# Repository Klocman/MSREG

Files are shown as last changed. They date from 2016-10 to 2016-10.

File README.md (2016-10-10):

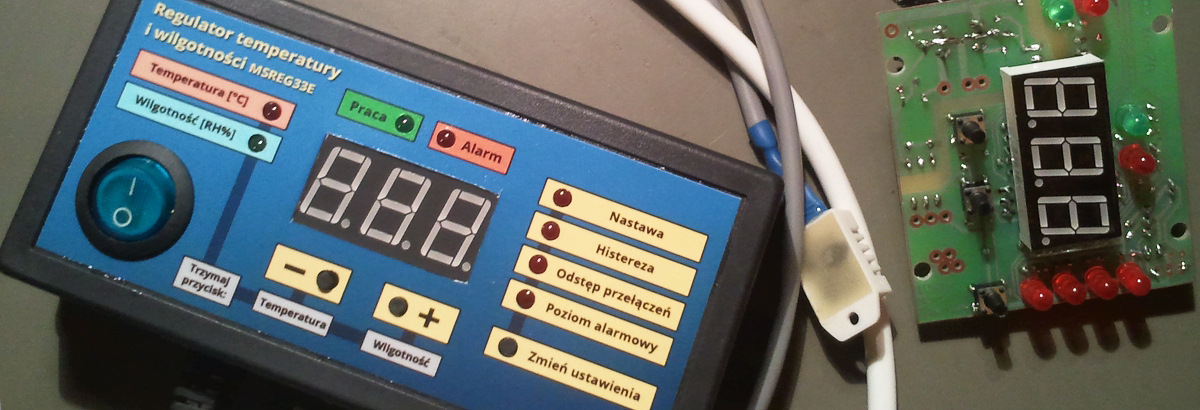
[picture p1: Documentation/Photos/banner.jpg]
Finished regulator, and a partially assembled board

## MSREG (Most recently MSREG33E)
Temperature and (optionally) humidity regulator based on DS18B20 or DHT22 sensors. This project contains the board layout, firmware, bootloader, and Windows tools that can be used with the regulator to monitor, configure, and update it. 

This regulator can be used for terrariums, heaters, egg incubators, refrigerators - anything that depends on stable temperature and/or humidity, and can be controlled by turning something On or Off.

## Features and technical specifications
[Read the datasheet (only in Polish at the moment)](https://github.com/Klocman/MSREG/blob/master/Documentation/datasheet_pl_msreg33E_r7.pdf)

## Compiling / Software required
Boards and schematics were created with Eagle PCB v6.6.0. 

Firmare and Bootloader can be opened and compiled with Atmel Studio 6 or newer. The bootloader .hex has to be manually merged with the main firmware .hex.

The Windows applications can be compiled in any modern version of Visual Studio with C# support.

## Photos and videos of the regulator
[Youtube video of MSREG33E working with the Windows application](https://youtu.be/d277WWdbOqA?t=52s)

[You can view the full gallery here](https://github.com/Klocman/MSREG/tree/master/Documentation/Photos)

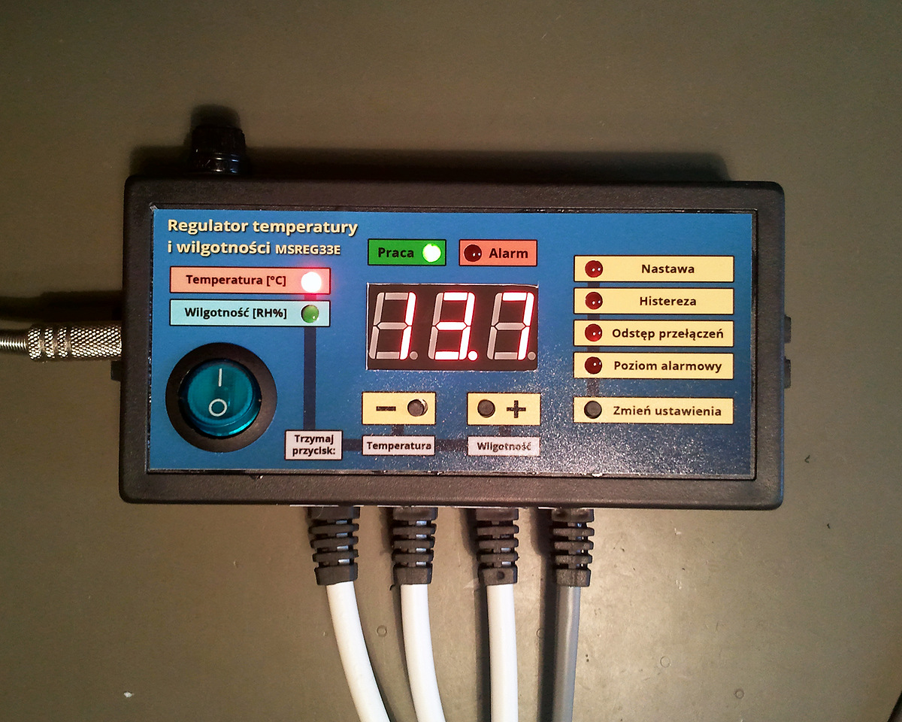
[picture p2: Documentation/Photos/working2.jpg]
Fully assembled and turned on

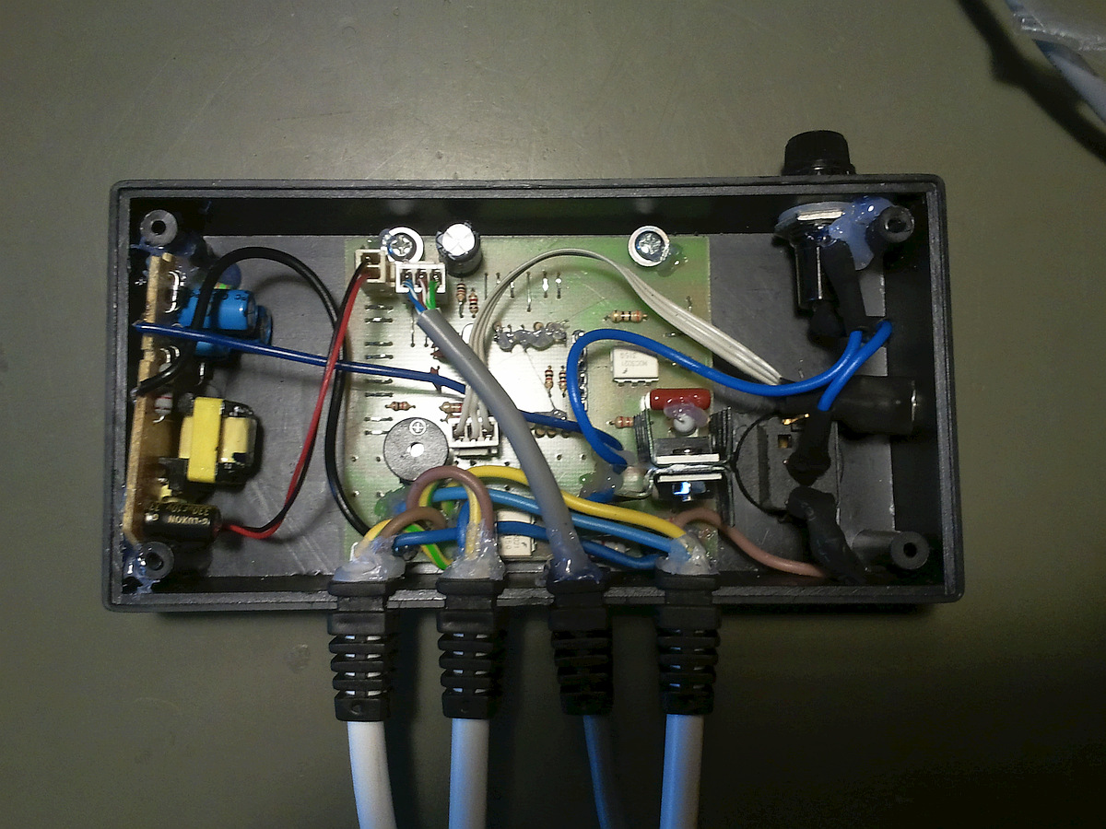
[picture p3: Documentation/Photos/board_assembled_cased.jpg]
Fully assembled with the back removed

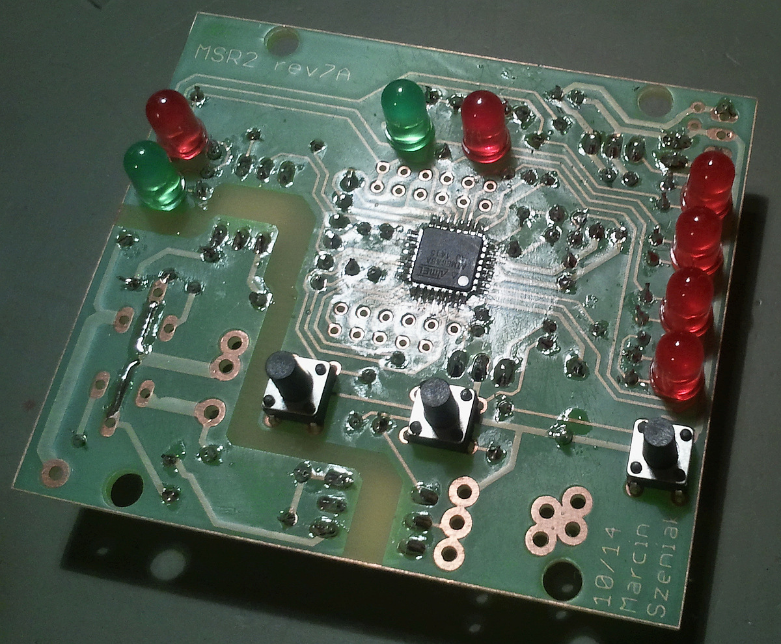
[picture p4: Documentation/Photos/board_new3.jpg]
Front of a partially assembled board

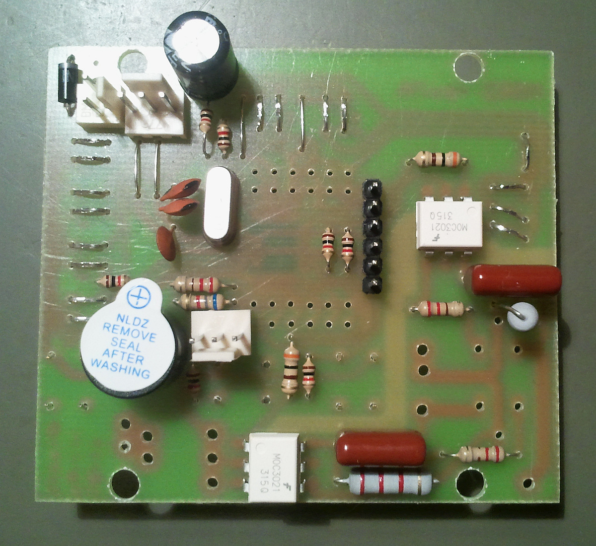
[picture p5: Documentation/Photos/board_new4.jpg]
Back of a partially assembled board


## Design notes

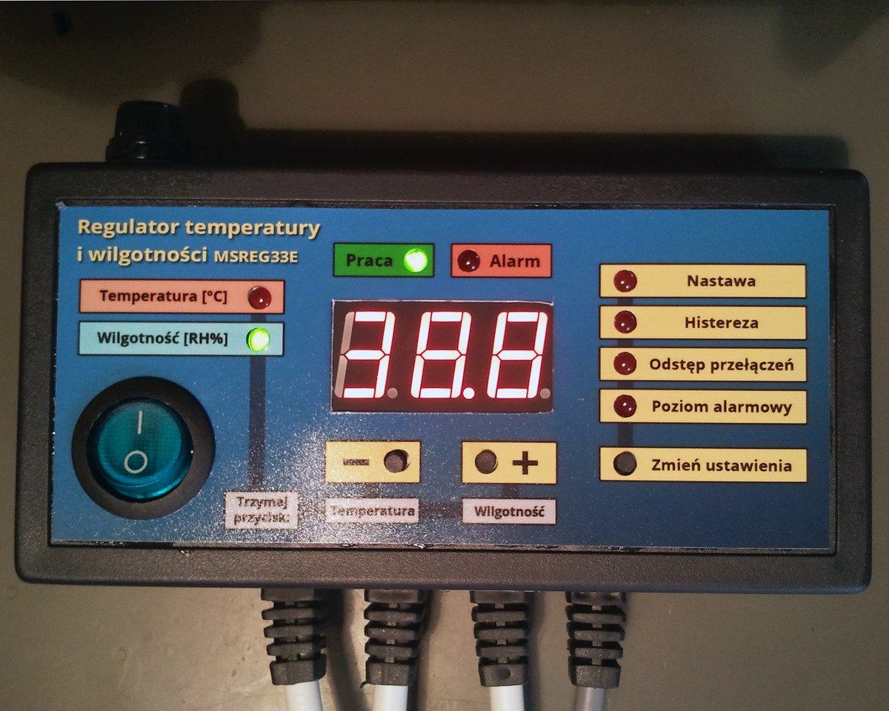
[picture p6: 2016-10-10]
Documentation/Photos/working1.jpg

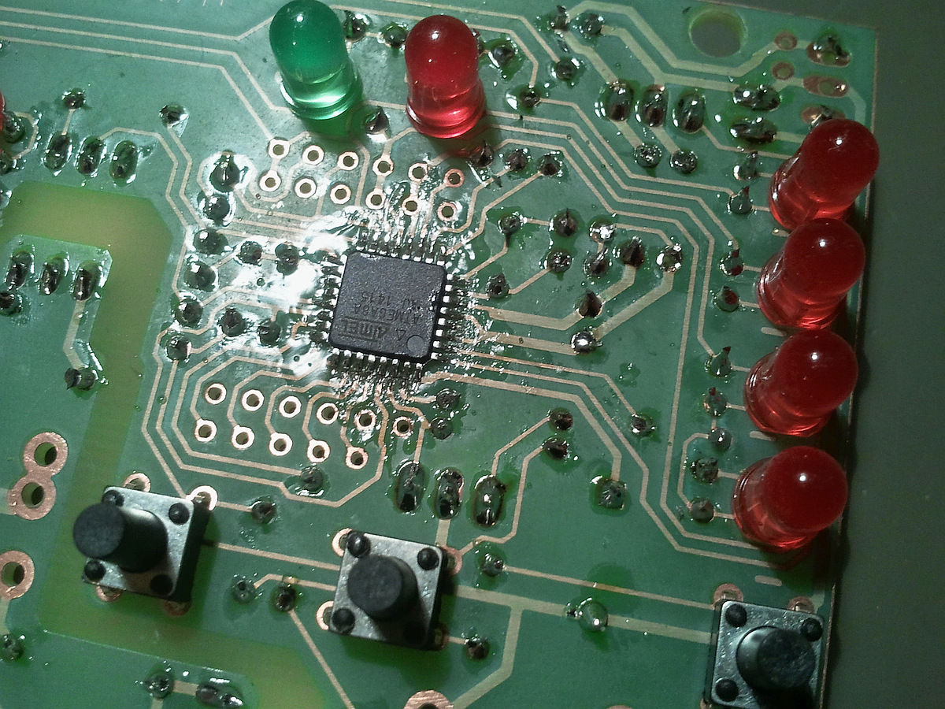
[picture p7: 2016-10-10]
Documentation/Photos/board_new2.jpg

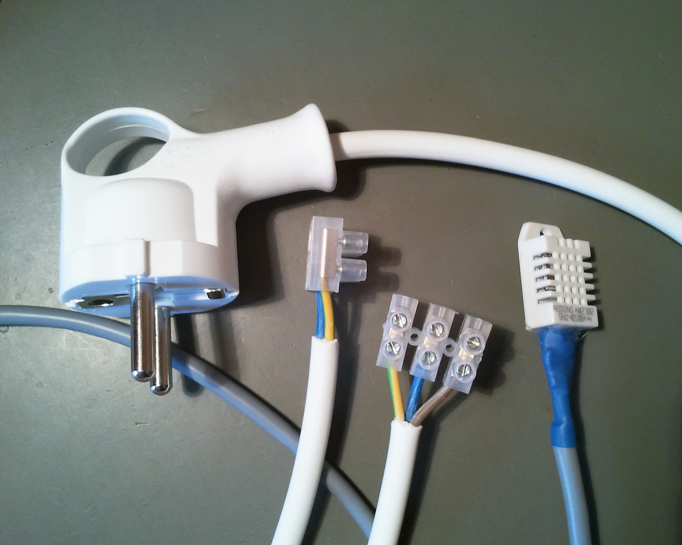
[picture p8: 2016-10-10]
Documentation/Photos/working6.jpg

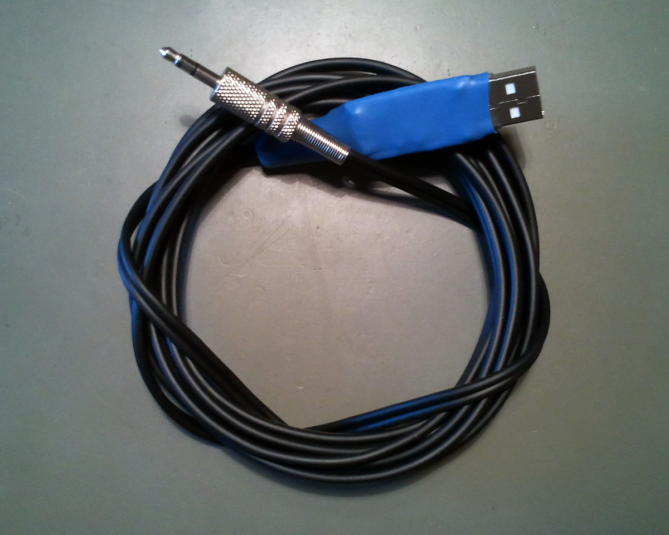
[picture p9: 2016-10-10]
Documentation/Photos/cable.jpg

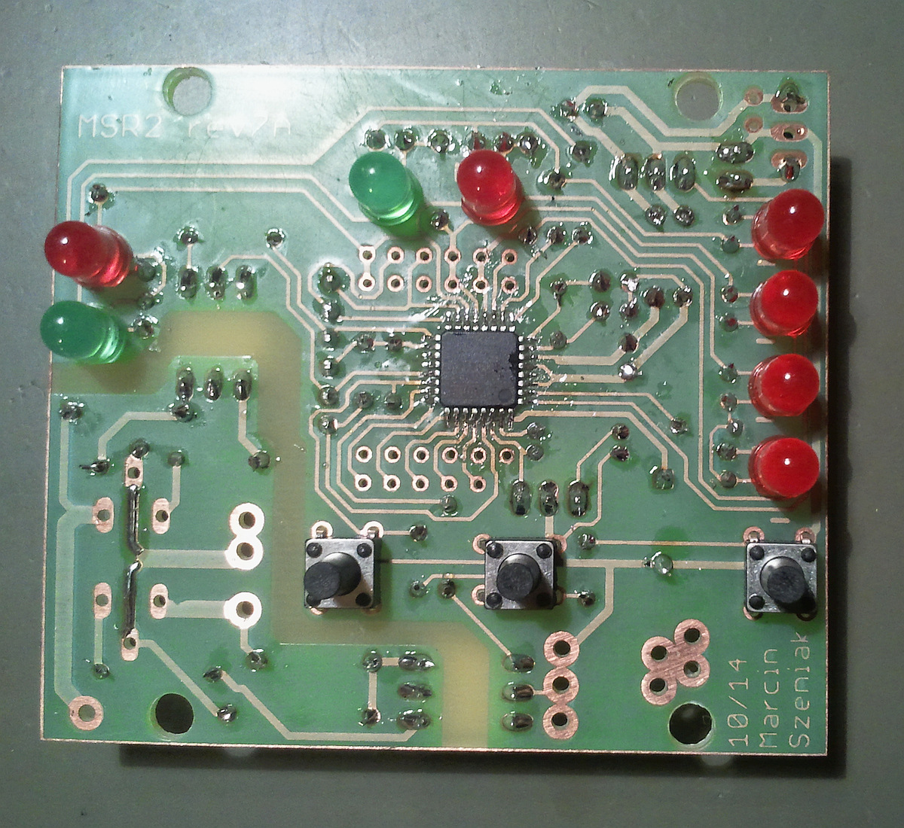
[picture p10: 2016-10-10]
Documentation/Photos/board_new1.jpg

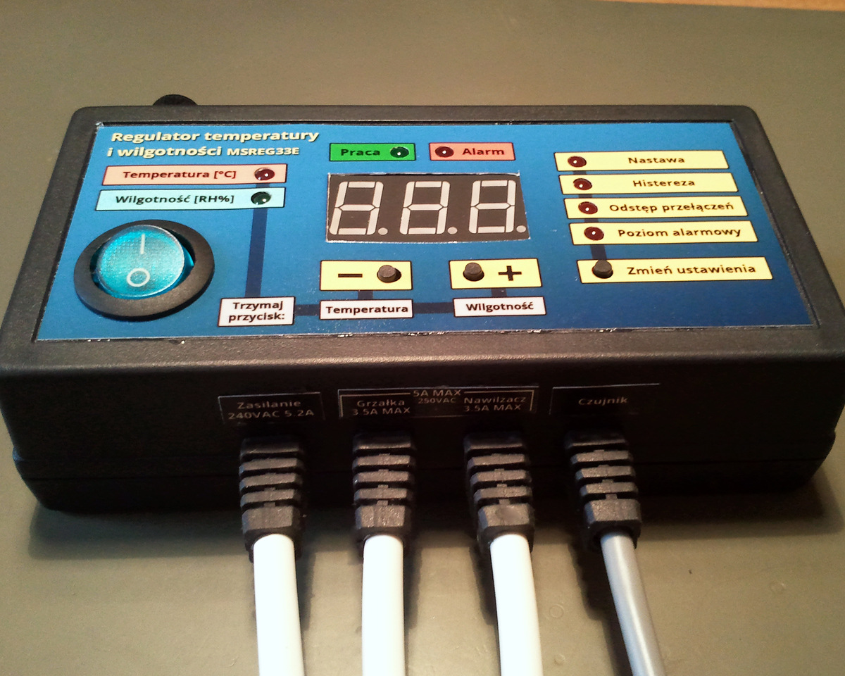
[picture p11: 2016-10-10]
Documentation/Photos/working3.jpg

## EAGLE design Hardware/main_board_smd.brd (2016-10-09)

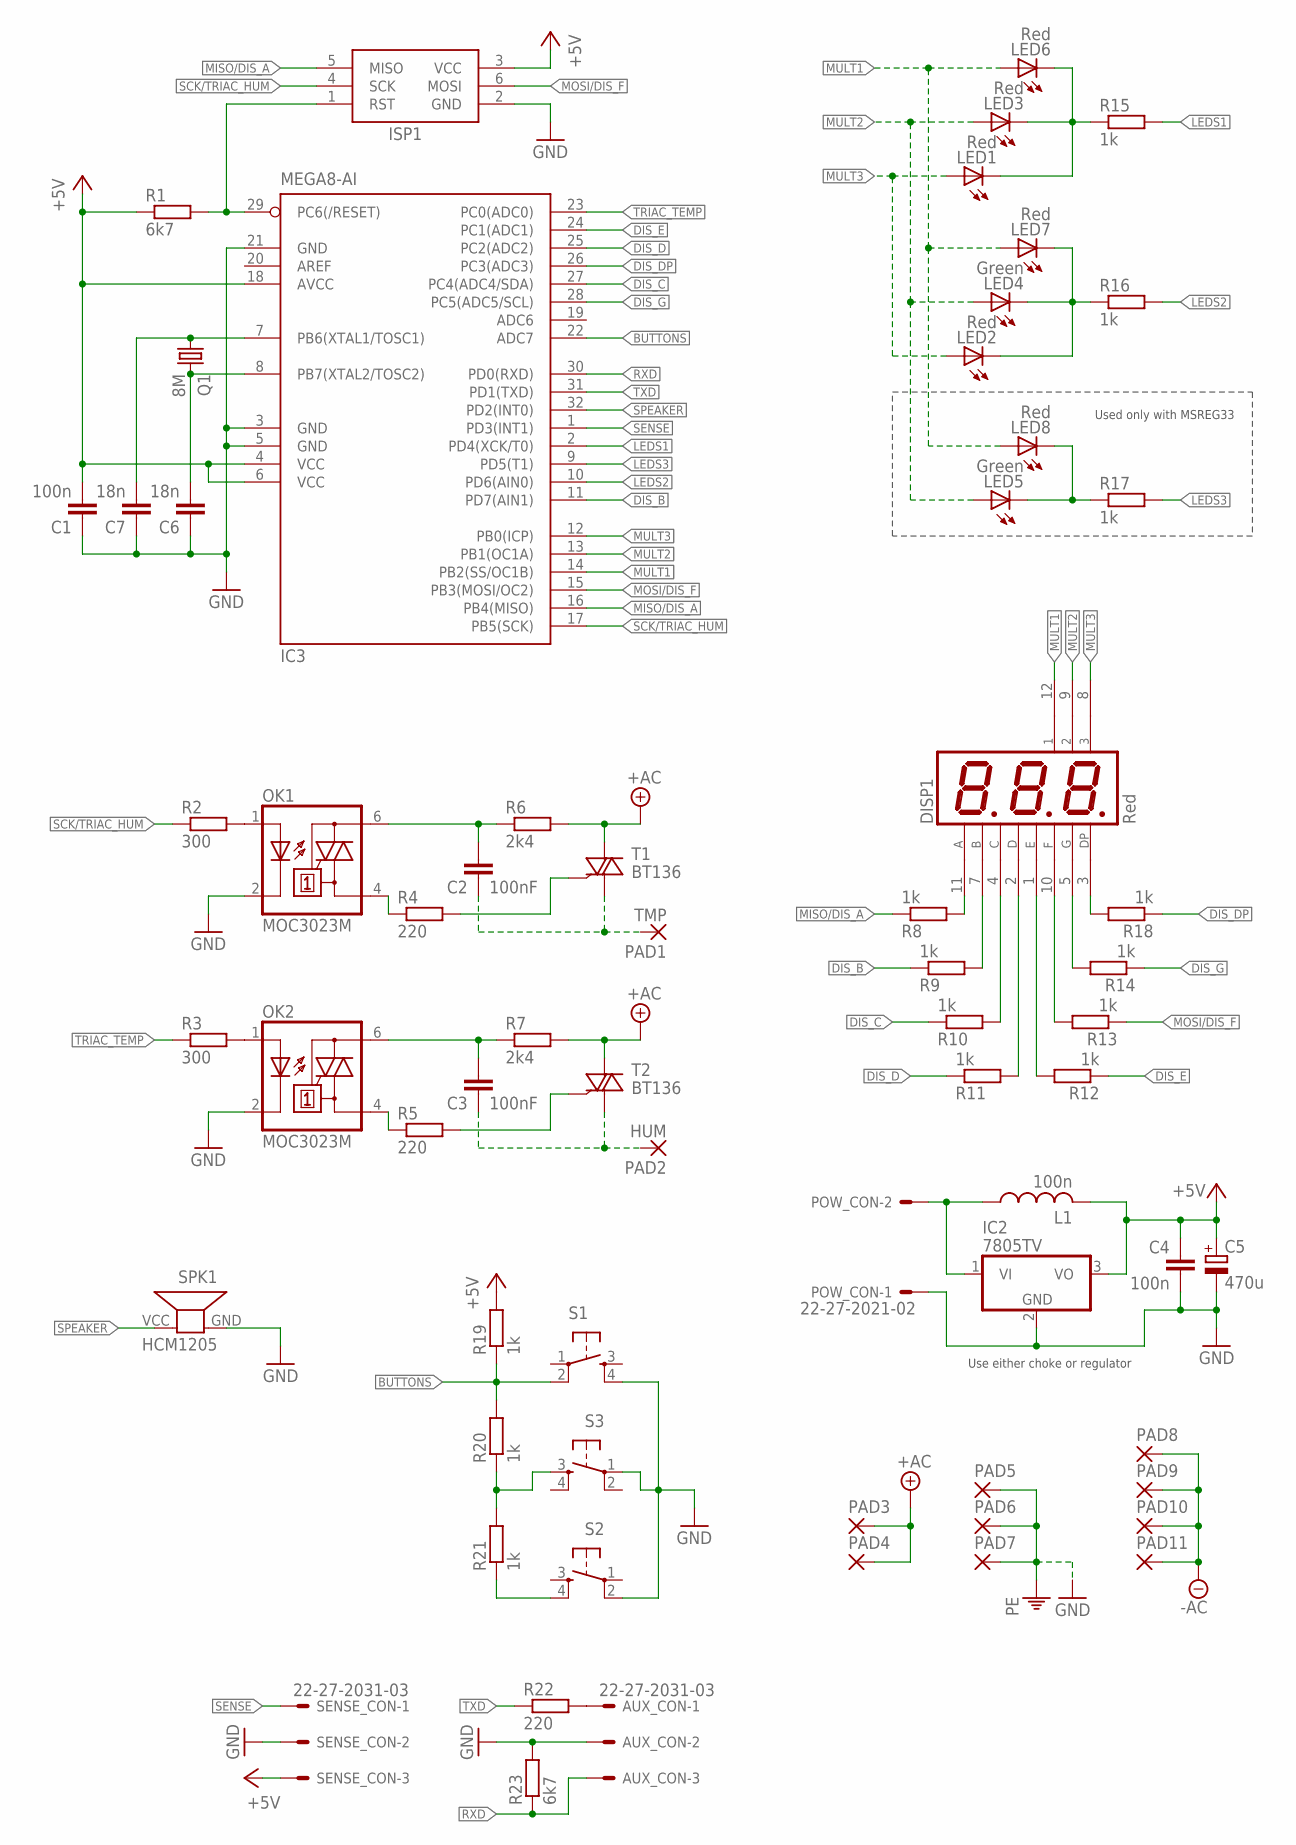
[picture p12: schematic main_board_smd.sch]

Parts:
AUX_CON: 22-27-2031-03; 6410-03
C1: 100n; C2.5-4
C2, C3: 100nF; C102-054X133
C4: 100n; C2.5-2
C5: 470u; TT2D7
C6, C7: 18n; C2.5-2
DISP1: Red; 7SEG3DIG
IC2: 7805TV; TO220V
IC3: MEGA8-AI; TQFP32-08
ISP1: AVRISPAV; AVRISP-KLOC
L1: 100n; 0204/7
LED1, LED2, LED3, LED6, LED7, LED8: Red; LED5MM
LED4, LED5: Green; LED5MM
OK1, OK2: MOC3023M; DIL06
PAD1: TMP; KLOCWIRE
PAD2: HUM; KLOCWIRE
PAD3, PAD4, PAD5, PAD6, PAD7, PAD8, PAD9, PAD10, PAD11: 3,17/1,3KLOC; KLOCWIRE
POW_CON: 22-27-2021-02; 6410-02
Q1: 8M; HC49U-V
R1: 6k7; 0204/5
R2, R3: 300; 0204/7
R4, R22: 220; 0204/7
R5: 220; 0207/10
R6: 2k4; 0411V
R7: 2k4; 0411/12
R8, R9, R10, R11, R12, R13, R14, R18: 1k; 0204V
R15, R16, R19, R20, R21: 1k; 0204/5
R17: 1k; 0204/7
R23: 6k7; 0204/7
S1, S2, S3: TAC_SWITCHPTH; TACTILE-PTH
SENSE_CON: 22-27-2031-03; 6410-03
SPK1: HCM1205; HCM12XX
T1, T2: BT136; TRIAC_VE

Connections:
+5V: C1.2, C4.1, C5.+, IC2.3 (VO), IC3.4 (VCC), IC3.6 (VCC), IC3.18 (AVCC), ISP1.3 (VCC), L1.2, R1.1, R19.2, SENSE_CON.3
+UB: PAD3.1, PAD4.1, R6.2, R7.2, T1.A (A2), T2.A (A2)
-UB: PAD8.1, PAD9.1, PAD10.1, PAD11.1
BUTTONS: IC3.22 (ADC7), R19.1, R20.2, S1.2
DIS_B: IC3.11 (PD7(AIN1)), R9.1
DIS_C: IC3.27 (PC4(ADC4/SDA)), R10.1
DIS_D: IC3.25 (PC2(ADC2)), R11.1
DIS_DP: IC3.26 (PC3(ADC3)), R18.1
DIS_E: IC3.24 (PC1(ADC1)), R12.1
DIS_G: IC3.28 (PC5(ADC5/SCL)), R14.1
GND: AUX_CON.2, C1.1, C4.2, C5.-, C6.1, C7.1, IC2.2 (GND), IC3.3 (GND), IC3.5 (GND), IC3.21 (GND), ISP1.2 (GND), OK1.2 (C), OK2.2 (C), PAD5.1, PAD6.1, PAD7.1, POW_CON.1, R23.2, S1.4, S2.2, S3.1, SENSE_CON.2, SPK1.GND
LEDS1: IC3.2 (PD4(XCK/T0)), R15.2
LEDS2: IC3.10 (PD6(AIN0)), R16.2
LEDS3: IC3.9 (PD5(T1)), R17.2
MISO/DIS_A: IC3.16 (PB4(MISO)), ISP1.5 (MISO), R8.1
MOSI/DIS_F: IC3.15 (PB3(MOSI/OC2)), ISP1.6 (MOSI), R13.1
MULT1: DISP1.12 (1), IC3.14 (PB2(SS/OC1B)), LED6.A, LED7.A, LED8.A
MULT2: DISP1.9 (2), IC3.13 (PB1(OC1A)), LED3.A, LED4.A, LED5.A
MULT3: DISP1.8 (3), IC3.12 (PB0(ICP)), LED1.A, LED2.A
unnamed: DISP1.3 (DP), R18.2
unnamed: DISP1.2 (D), R11.2
unnamed: DISP1.4 (C), R10.2
unnamed: DISP1.7 (B), R9.2
unnamed: DISP1.11 (A), R8.2
unnamed: DISP1.1 (E), R12.2
unnamed: DISP1.10 (F), R13.2
unnamed: DISP1.5 (G), R14.2
unnamed: C7.2, IC3.7 (PB6(XTAL1/TOSC1)), Q1.1
unnamed: C6.2, IC3.8 (PB7(XTAL2/TOSC2)), Q1.2
unnamed: LED1.K (C), LED3.K (C), LED6.K (C), R15.1
unnamed: LED5.K (C), LED8.K (C), R17.1
unnamed: IC2.1 (VI), L1.1, POW_CON.2
unnamed: LED2.K (C), LED4.K (C), LED7.K (C), R16.1
unnamed: C2.1, OK1.6 (A2), R6.1
unnamed: C2.2, PAD1.1, T1.C (A1)
unnamed: OK2.1 (A), R3.2
unnamed: OK2.4 (A1), R5.1
unnamed: R5.2, T2.G
unnamed: OK1.4 (A1), R4.1
unnamed: C3.1, OK2.6 (A2), R7.1
unnamed: C3.2, PAD2.1, T2.C (A1)
unnamed: AUX_CON.1, R22.2
unnamed: R4.2, T1.G
unnamed: R20.1, R21.2, S3.3
unnamed: R21.1, S2.4
unnamed: OK1.1 (A), R2.2
RESET: IC3.29 (PC6(/RESET)), ISP1.1 (RST), R1.2
RXD: AUX_CON.3, IC3.30 (PD0(RXD)), R23.1
SCK/TRIAC_HUM: IC3.17 (PB5(SCK)), ISP1.4 (SCK), R2.1
SENSE: IC3.1 (PD3(INT1)), SENSE_CON.1
SPEAKER: IC3.32 (PD2(INT0)), SPK1.VCC
TRIAC_TEMP: IC3.23 (PC0(ADC0)), R3.1
TXD: IC3.31 (PD1(TXD)), R22.1

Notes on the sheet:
Use either choke or regulator
Used only with MSREG33

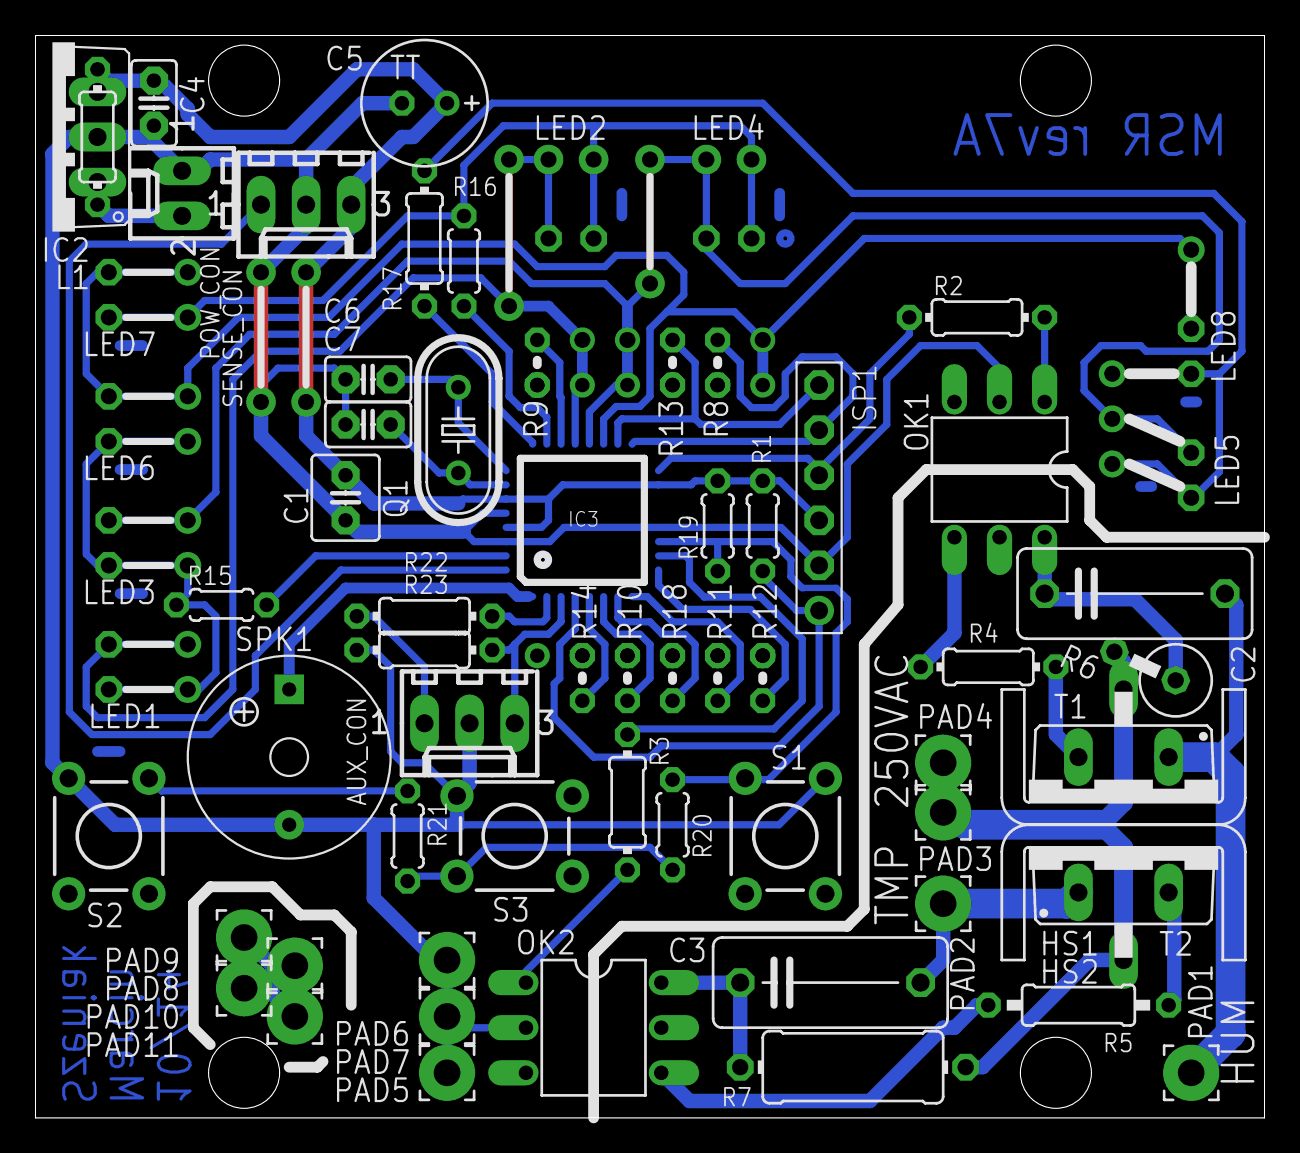
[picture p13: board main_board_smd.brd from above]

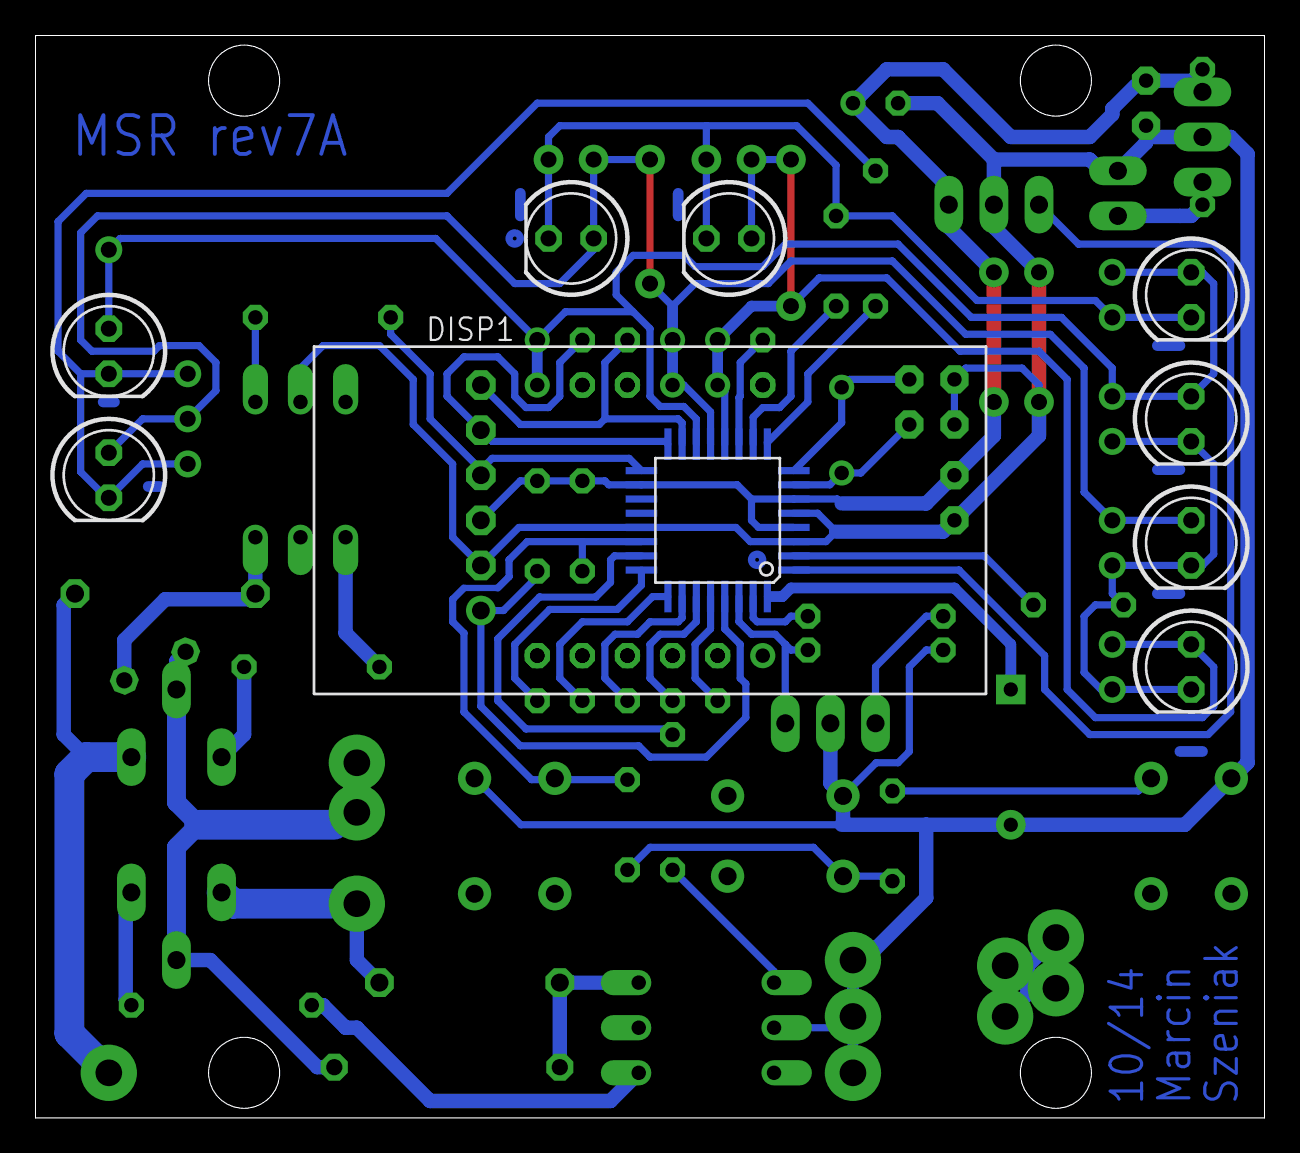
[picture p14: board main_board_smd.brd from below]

Board: 2 copper layers, 69.2 x 61.0 mm, 68 parts (10 on the bottom side), 53 nets.

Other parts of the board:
HS1, HS2: D03S

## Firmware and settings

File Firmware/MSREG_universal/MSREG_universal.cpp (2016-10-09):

/*
* MSREG_universal.cpp
*
* Created: 20-09-14 12:55:07 PM
*  Author: Klocman
*/

#define F_CPU 8000000UL

#include <avr/io.h>
#include <avr/interrupt.h>
#include <avr/eeprom.h>
#include <avr/wdt.h>
#include <avr/pgmspace.h>
#include <stdio.h>

#include "Version/VersionInfo.h"
#include "PinConfiguration.h"

#include "Libs/7SEG.h"
#include "KlocTools.h"
#include "Classes.h"
#include "Libs/DHT22.h"
#include "Tools/RollingAverage.h"

#include "Libs/ExternalDeviceConnector.h"

#define REGULATION_TIMER_MAX 300
#define REGULATION_TIMER_MIN 0

#define UART_BUFFER_SIZE 34

const char newLine_P[] PROGMEM = "\r\n";
const char okResponse_P[] PROGMEM = "OK\r\n";

ExternalDeviceConnector extConnector;
LedIndicators ledIndicators;
Speaker speaker;
OutputTriac triacTemp;
OutputTriac triacHum;
Timer timerTemp;
Timer timerHum;
Timer sensorRefreshTimer;

RegulationSettings regSettingsTemp;
RegulationSettings regSettingsHum;

uint8_t saveSettingsQueued = 0;
uint8_t bootCompleted = 0;

//RollingAverage sensorResultAverageTemperature;
//RollingAverage sensorResultAverageHumidity;

//RollingAverage sensorAverage;

char buffor[UART_BUFFER_SIZE+1];

void OnWaitTimeChanged();
void OnReturnedToMainMenu();
void OnAlarmStarted ()
{
	speaker.PlayContinous();
	extConnector.SetDumbAlarm(1);
}
void OnAlarmEnded ()
{
	speaker.StopPlaying();
	extConnector.SetDumbAlarm(0);
}

#pragma region Alarm

enum AlarmType
{
	AlarmType_None = 0,
	AlarmType_BOOT_FAILED = 1,
	AlarmType_SENSOR_FAILURE = 2,
	AlarmType_TEMPERATURE_REGULATION = 3,
	AlarmType_HUMIDITY_REGULATION = 4,
	AlarmType_SOFTWARE_FAIL = 6,
	AlarmType_OTHER = 7
};

class AlarmSystem
{
	uint8_t activeFlags;
	//Action OnAlarmStarted;
	//Action OnAlarmEnded;
	
	public:
	/*inline void Init (Action onAlarmStartedCallback, Action onAlarmEndedCallback)
	{
		OnAlarmStarted = onAlarmStartedCallback;
		OnAlarmEnded = onAlarmEndedCallback;
		activeFlags = 0;
	}*/
	// Set AlarmType_None to clear all of the flags
	inline void SetAlarmFlag (AlarmType flag)
	{
		if (flag != AlarmType_None)
		{
			if (!activeFlags)
			{
				OnAlarmStarted();
			}
			BIT_HIGH(activeFlags, flag);
		}
	}
	inline void ClearAlarmFlag (AlarmType flag)
	{
		if (flag != AlarmType_None)
		{
			if (activeFlags)
			{
				BIT_LOW(activeFlags, flag);
				if (!activeFlags)
				{
					OnAlarmEnded();
				}
			}
		}
	}
	inline void ClearAllFlags ()
	{
		activeFlags = 0;
	}
	inline uint8_t GetActiveFlags () const
	{
		return activeFlags;
	}
	inline uint8_t GetActiveCriticalFlags () const
	{
		return activeFlags & ~((1<<AlarmType_HUMIDITY_REGULATION) | (1<<AlarmType_TEMPERATURE_REGULATION));
	}
	// Get number of the most significant set alarm flag. If no flags are set, 0 is returned.
	uint8_t GetAlarmDigit () const
	{
		if (activeFlags)
		{
			for(uint8_t i = 0; i < 8; i++)
			{
				if (BIT_READ(activeFlags, i))
				{
					return i;
				}
			}
		}
		return 0;
	}
};

AlarmSystem alarm;

#pragma endregion Alarm

#pragma region EEPROM

#define EEvalidValue 0x12
uint8_t EEMEM EEvalid;
RegulationSettings EEMEM EeTempConfig;
RegulationSettings EEMEM EeHumConfig;

inline void SaveSettings ()
{
	/*
	RegulationSettingsExtract te,he;
	te = regSettingsTemp.GetExtract();
	he = regSettingsHum.GetExtract();
	
	// EEPROM is not valid, make it valid
	uint8_t isInvalid = (eeprom_read_byte(&EEvalid) != EEvalidValue);
	
	RegulationSettingsExtract t,h;
	eeprom_read_block(&t, &EeTempConfig, sizeof(RegulationSettingsExtract));
	eeprom_read_block(&h, &EeHumConfig, sizeof(RegulationSettingsExtract));
	
	if(isInvalid || !te.Equals(&t))
	{
	eeprom_write_block(&te, &EeTempConfig, sizeof(RegulationSettingsExtract));
	}
	
	if (isInvalid || !he.Equals(&h))
	{
	eeprom_write_block(&he, &EeHumConfig, sizeof(RegulationSettingsExtract));
	}
	
	if (isInvalid)
	{
	eeprom_write_byte(&EEvalid, EEvalidValue);
	}*/
	
	eeprom_write_block(&regSettingsTemp, &EeTempConfig, sizeof(RegulationSettings));
	eeprom_write_block(&regSettingsHum, &EeHumConfig, sizeof(RegulationSettings));
	eeprom_write_byte(&EEvalid, EEvalidValue);
}

void ReadDefaultSettings ()
{
	regSettingsTemp.Init(DHT22_TEMP_MIN, DHT22_TEMP_MAX, DHT22_TEMP_HIST_MAX, REGULATION_TIMER_MAX);
	regSettingsHum.Init(DHT22_HUM_MIN, DHT22_HUM_MAX, DHT22_HUM_HIST_MAX, REGULATION_TIMER_MAX);
	
	regSettingsTemp.alarmOffset.variable = 0;
	regSettingsTemp.histeresis.variable = 1;
	regSettingsTemp.targetValue.variable = 366;
	regSettingsTemp.waitTime.variable = 0;
	regSettingsTemp.normallyClosed.variable = 0;
	
	regSettingsHum.alarmOffset.variable = 0;
	regSettingsHum.histeresis.variable = 5;
	regSettingsHum.targetValue.variable = 500;
	regSettingsHum.waitTime.variable = 0;
	regSettingsHum.normallyClosed.variable = 0;
	
	OnWaitTimeChanged();
}

void ReadSettings ()
{
	if(eeprom_read_byte(&EEvalid) != EEvalidValue)
	{
		// EEPROM is not valid, read fail safe settings
		ReadDefaultSettings();
	}
	else
	{
		eeprom_read_block(&regSettingsTemp, &EeTempConfig, sizeof(RegulationSettings));
		eeprom_read_block(&regSettingsHum, &EeHumConfig, sizeof(RegulationSettings));
		
		OnWaitTimeChanged();
	}
}

#pragma endregion EEPROM

#pragma region Seven segment menu

enum DisplayedVariable
{
	Display_Temperature = 0,
	Display_TemperatureValue = 1,
	Display_TemperatureHist = 2,
	Display_TemperatureTime = 3,
	Display_TemperatureAlarm = 4,
	
	Display_Humidity = 10,
	Display_HumidityValue = 11,
	Display_HumidityHist = 12,
	Display_HumidityTime = 13,
	Display_HumidityAlarm = 14,
	
	Display_OtherAlarm = 20
};

class SevSegMenu
{
	private:
	uint8_t currentlyDisplayed;
	uint8_t forcedAlarm;
	SevenSegmentDisplay sevSegDisplay;
	
	Timer menuTimeout;
	
	inline void TimeoutTimerElapsed ()
	{
		if (currentlyDisplayed > Display_Temperature && currentlyDisplayed < Display_Humidity)
		{
			currentlyDisplayed = Display_Temperature;
			OnReturnedToMainMenu();
		}
		else if (currentlyDisplayed > Display_Humidity && currentlyDisplayed < Display_OtherAlarm)
		{
			currentlyDisplayed = Display_Humidity;
			OnReturnedToMainMenu();
		}
		//else // We are already in the main menu!
	}
	
	public:
	inline void Init ()
	{
		currentlyDisplayed = Display_Temperature;
		sevSegDisplay.SetupPins();
		
		menuTimeout.Init();
		menuTimeout.SetCounterTop(50);
	}
	inline void DrawOutput (const uint8_t currentMultiplex) const
	{
		sevSegDisplay.DrawOutput(currentMultiplex);
	}
	inline void SetAlarm (uint8_t alarmNumber)
	{
		forcedAlarm = alarmNumber;
	}
	inline void Tick ()
	{
		menuTimeout.Tick();
	}
	inline void MainMenuUpdate (ButtonEvent input, const DHT22result *sensorResult)
	{
		//sevSegDisplay.WriteVariable(123, 1, 0);
		
		if (forcedAlarm)
		{
			sevSegDisplay.WriteError(forcedAlarm);
			return;
		}
		
		if (!bootCompleted)
		{
			return;
		}
		
		// Menu timeout (auto return to main menu after inactivity)
		if (input != BUTTON_NONE)
		{
			menuTimeout.ResetCounter();
		}
		else
		{
			if (!menuTimeout.IsRunning())
			{
				TimeoutTimerElapsed(); // Does nothing unless not in main menu, so it can be ran frequently
			}
		}
		
		SingleSetting *targetSetting = 0;
		{
			RegulationSettings *targetSetings;
			if (currentlyDisplayed < Display_Humidity)
			{
				targetSetings = &regSettingsTemp;
			}
			else
			{
				targetSetings = &regSettingsHum;
			}
			
			switch(currentlyDisplayed)
			{
				case Display_TemperatureAlarm:
				case Display_HumidityAlarm:
				targetSetting = &targetSetings->alarmOffset;
				break;
				case Display_TemperatureHist:
				case Display_HumidityHist:
				targetSetting = &targetSetings->histeresis;
				break;
				case Display_TemperatureTime:
				case Display_HumidityTime:
				targetSetting = &targetSetings->waitTime;
				break;
				
				case Display_TemperatureValue:
				case Display_HumidityValue:
				targetSetting = &targetSetings->targetValue;
				break;
				
				default:
				break;
			}
		}
		
		switch(input)
		{
			case BUTTON_HOME_SINGLE:
			if (currentlyDisplayed >= Display_OtherAlarm)
			{
				currentlyDisplayed = Display_Temperature;
				OnReturnedToMainMenu();
			}
			else
			{
				currentlyDisplayed += 1;
				if (currentlyDisplayed == 5 || currentlyDisplayed == 15)
				{
					// Return to the main menu
					currentlyDisplayed -=5;
					OnReturnedToMainMenu();
				}
			}
			break;
			
			case BUTTON_HOME_ONHOLD:
			case BUTTON_HOME_RAPID:
			break;
			
			// Remove 1
			case BUTTON_LEFT_RAPID:
			case BUTTON_LEFT_SINGLE:
			if (targetSetting)
			{
				targetSetting->Sub1();
				OnWaitTimeChanged();
			}
			break;
			
			// Add 1
			case BUTTON_RIGHT_RAPID:
			case BUTTON_RIGHT_SINGLE:
			if (targetSetting)
			{
				targetSetting->Add1();
				OnWaitTimeChanged();
			}
			break;
			
			case BUTTON_LEFT_ONHOLD:
			if (currentlyDisplayed == Display_Humidity)
			currentlyDisplayed = Display_Temperature;
			break;
			
			case BUTTON_RIGHT_ONHOLD:
			if (currentlyDisplayed == Display_Temperature)
			currentlyDisplayed = Display_Humidity;
			break;
			
			default:
			break;
		}
		
		// Repaint display output
		switch(currentlyDisplayed)
		{
			case Display_Temperature:
			sevSegDisplay.WriteVariable(sensorResult->temperature, DHT22_RESULT_DECIMALPOINT_PLACE, 0);
			break;
			case Display_Humidity:
			sevSegDisplay.WriteVariable(sensorResult->humidity, DHT22_RESULT_DECIMALPOINT_PLACE, 0);
			break;
			
			// Settings: Time, hist, value and alarm
			default:
			if (targetSetting)
			{
				// If setting is a value, pass 0 to writeVariable, else pass 1 to replace 0 with "OFF"
				sevSegDisplay.WriteVariable(targetSetting->variable, DHT22_RESULT_DECIMALPOINT_PLACE,
				!(currentlyDisplayed == Display_HumidityValue || currentlyDisplayed == Display_TemperatureValue));
			}
			else
			{
				//sevSegDisplay.WriteError(9); if set, flashes briefly when entering settings
			}
			break;
		}
	}
	
	inline void TurnOnMenuLeds () const
	{
		if (currentlyDisplayed < Display_Humidity) // Temperature related
		{
			ledIndicators.TurnOn(LED_ShowTemp);
		}
		else if (currentlyDisplayed < Display_OtherAlarm) // Humidity related
		{
			ledIndicators.TurnOn(LED_ShowHum);
		}
		
		switch(currentlyDisplayed)
		{
			case Display_TemperatureAlarm:
			case Display_HumidityAlarm:
			ledIndicators.TurnOn(LED_SetAlarm);
			break;
			
			case Display_TemperatureHist:
			case Display_HumidityHist:
			ledIndicators.TurnOn(LED_SetHist);
			break;
			
			case Display_TemperatureTime:
			case Display_HumidityTime:
			ledIndicators.TurnOn(LED_SetTime);
			break;
			
			case Display_TemperatureValue:
			case Display_HumidityValue:
			ledIndicators.TurnOn(LED_SetValue);
			break;
			
			default:
			break;
		}
	}
};

SevSegMenu sevSegMenu;

#pragma endregion Seven segment menu

#pragma region Regulation logic

uint8_t regulationOverride = 0;

inline void DisableRegulationOverride()
{
	regulationOverride = 0;
	TCCR1B = 0;
}
inline void EnableRegulationOverride()
{
	regulationOverride = 1;
	TCNT1 = 0;
	// 5 seconds with 1024 prescaler
	OCR1A = 39063;
	// T1 CTC
	BIT_HIGH(TCCR1A, WGM12);
	// T1 OCR1 interrupt
	BIT_HIGH(TIMSK, OCIE1A);
	// T1 1024 prescaler, start timer
	BIT_HIGH(TCCR1B, CS10);
	BIT_HIGH(TCCR1B, CS12);
}

//////////////////////////////////////////////////////////////////////////
// Regulation logic
// Hysteresis and alarm should always be >= 0 (0 for disabled)
RegulationResult ProcessRegulationData ( const int16_t measuredValue, const RegulationSettings *settings)
{
	if (!regulationOverride)
	{
		if (settings->histeresis.variable <= 0 || !bootCompleted)
		{
			return Result_Disable;
		}
		
		if (measuredValue <= settings->targetValue.variable)
		{
			if ((settings->alarmOffset.variable > 0) && (measuredValue <= settings->targetValue.variable - settings->alarmOffset.variable))
			{
				return Result_BelowSettingAlarm;
			}
			return Result_BelowSetting;
		}
		else if (measuredValue >= (settings->targetValue.variable + settings->histeresis.variable))
		{
			if ((settings->alarmOffset.variable > 0) && (measuredValue >= settings->targetValue.variable + settings->histeresis.variable + settings->alarmOffset.variable))
			{
				return Result_AboveSettingAlarm;
			}
			return Result_AboveSetting;
		}
	}
	
	return Result_DoNothing;
	
	/* // Old regulation logic
	if (!histeresis)
	{
	return Result_Disable;
	}
	
	uint8_t tempHist = dht22_setting_temperature_histeresis/2;
	
	// If above set temperature + half histeresis (round up)
	if ((sensor_values.temperature - (tempHist + (dht22_setting_temperature_histeresis % 2) ? 1 : 0)) > dht22_setting_temperature_value)
	{
	// Set alarm flag if temperature goes too far out
	if (dht22_setting_temperature_alarm && (sensor_values.temperature - dht22_setting_temperature_alarm) > dht22_setting_temperature_value)
	return Result_AboveSettingAlarm;
	else
	return Result_AboveSetting;
	}
	// If below set temperature + half histeresis (round down)
	else if ((sensor_values.temperature + tempHist) <= dht22_setting_temperature_value)
	{
	if (dht22_setting_temperature_alarm && (sensor_values.temperature + dht22_setting_temperature_alarm) <= dht22_setting_temperature_value)
	return Result_BelowSettingAlarm;
	else
	return Result_BelowSetting;
	}
	
	return Result_DoNothing;
	*/
}

RegulationResult RegulationUpdate(const AlarmType regulationType, const DHT22result *sensorResult)
{
	RegulationResult result = Result_AboveSettingAlarm;//Result_WaitForTimer;
	
	OutputTriac *outTriac;
	Timer *outTimer;
	
	if (regulationType == AlarmType_TEMPERATURE_REGULATION)
	{
		result = ProcessRegulationData(sensorResult->temperature, &regSettingsTemp);
		outTimer = &timerTemp;
		outTriac = &triacTemp;
	}
	else //if (regulationType == AlarmType_HUMIDITY_REGULATION)
	{
		result = ProcessRegulationData(sensorResult->humidity, &regSettingsHum);
		outTimer = &timerHum;
		outTriac = &triacHum;
	}
	/*else
	{
		alarm.SetAlarmFlag(AlarmType_SOFTWARE_FAIL);
		return;
	}*/

	uint8_t triacPreviousState = outTriac->GetState();
	
	if (!outTimer->IsRunning())
	{
		switch(result)
		{
			case Result_AboveSettingAlarm:
			outTriac->SetOutput(0);
			alarm.SetAlarmFlag(regulationType);
			break;
			
			case Result_AboveSetting:
			outTriac->SetOutput(0);
			alarm.ClearAlarmFlag(regulationType);
			break;
			
			case Result_BelowSettingAlarm:
			outTriac->SetOutput(1);
			alarm.SetAlarmFlag(regulationType);
			break;
			
			case Result_BelowSetting:
			outTriac->SetOutput(1);
			alarm.ClearAlarmFlag(regulationType);
			break;
			
			case Result_DoNothing:
			// Clear alarm since when doing nothing we have to be in the hysteresis range
			alarm.ClearAlarmFlag(regulationType);
			break;
			
			default:
			case Result_WaitForTimer:
			break;
			
			case Result_Disable:
			outTriac->Disable();
			alarm.ClearAlarmFlag(regulationType);
			break;
		}
		
		if (triacPreviousState != outTriac->GetState())
		{
			outTimer->ResetCounter();
		}
	}
	else
	{
		result = Result_WaitForTimer;
	}
	
	return result;
}

#pragma endregion Regulation logic

#pragma region Uart control
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
int main(void)
{
	// Enable watchdog (restart avr if program hangs for 2 seconds)
	wdt_enable(WDTO_2S);
	
	Buttons buttons;
	DHT22sensor sensor;
	
	//uart_init(UART_BAUD_SELECT(USART_BAUDRATE, F_CPU));
	extConnector.Init();
	
	// Initialize all connected devices
	//alarm.Init(OnAlarmStarted, OnAlarmEnded);
	alarm.ClearAllFlags();
	sevSegMenu.Init();
	ledIndicators.Init();
	buttons.Init();
	
	sensor.Init();
	sensorRefreshTimer.Init();
	sensorRefreshTimer.SetCounterTop(DHT22_REFRESHTIME);
	
	timerHum.Init();
	timerTemp.Init();
	
	speaker.InitSpeaker();
	speaker.PlayTone();
	
	//sensorResultAverageTemperature.Init();
	//sensorResultAverageHumidity.Init();
	
	MULTIPLEX_Setup();
	Timer_Setup();
	
	//ReadDefaultSettings(); done in readsettings if needed
	ReadSettings();
	
	triacTemp.InitPorts(&TRIAC_TEMP_PORT, &TRIAC_TEMP_DDR, TRIAC_TEMP_PIN, &regSettingsTemp.normallyClosed.variable);
	triacHum.InitPorts(&TRIAC_HUM_PORT, &TRIAC_HUM_DDR, TRIAC_HUM_PIN, &regSettingsHum.normallyClosed.variable);
	
	DHT22result sensorResult = {0,0};
	
	sei();
	//alarm.SetAlarmFlag(AlarmType_SOFTWARE_FAIL);
	//DHT22result tempResult = {0,0};
	while (1)
	{
		wdt_reset();
		uint8_t sendSensorDataOverUart = 0;
		
		if (!sensorRefreshTimer.IsRunning())
		{
			SensorResult sr = sensor.ReadSensor(&sensorResult);
			switch(sr)
			{
				case SensorOK:
				alarm.ClearAlarmFlag(AlarmType_SENSOR_FAILURE);
				bootCompleted = 1; // Enable regulation updates
				sendSensorDataOverUart = 1;
				sensorRefreshTimer.ResetCounter();
				//sensorAverage.ProcessValue(&sensorResult);
				break;
				
				default:
				alarm.SetAlarmFlag(AlarmType_SENSOR_FAILURE);
				
				sprintf_P(buffor, PSTR("E%u"), sr); // Newline gets added in SendAlarmInfo
				extConnector.uPuts(buffor); //uart_puts
				SendAlarmInfo();
				
				case SensorBusy:
				sensorRefreshTimer.AddTicks(20); // Reduce the error flood
				break;
			}
		}
		
		// If alarm is because of bad regulation, show normal menu instead of error code
		sevSegMenu.SetAlarm(alarm.GetActiveCriticalFlags());
		
		// Beep the speaker if buttons are pressed
		ButtonEvent currentButtonEvent = buttons.ProcessInputs();
		
		if (currentButtonEvent > BUTTON_MULTIPLE && currentButtonEvent < BUTTON_LEFT_RAPID )
		{
			speaker.PlayTone();
		}
		
		sevSegMenu.MainMenuUpdate(currentButtonEvent, &sensorResult);
		
		//////////////////////////////////////////////////////////////////////////
		// Regulation
		//_delay_ms(1);
		RegulationResult resTemp, resHum;
		
		resTemp = RegulationUpdate(AlarmType_TEMPERATURE_REGULATION, &sensorResult);
		resHum = RegulationUpdate(AlarmType_HUMIDITY_REGULATION, &sensorResult);
		
		//////////////////////////////////////////////////////////////////////////
		// Repaint LEDs
		sevSegMenu.TurnOnMenuLeds();
		
		if (alarm.GetActiveFlags())
		{
			ledIndicators.TurnOn(LED_Alarm);
		}
		
		if (triacTemp.GetState() || triacHum.GetState())
		{
			ledIndicators.TurnOn(LED_Praca);
		}
		ledIndicators.PushChanges();
		
		//////////////////////////////////////////////////////////////////////////
		// Update UART
		if (sendSensorDataOverUart)
		{
			//snprintf_P(buffor, UART_BUFFER_SIZE, PSTR("T%.3u.%u H%.3u.%u "),
			//extConnector.uPuts(buffor);
			
			//snprintf_P(buffor, UART_BUFFER_SIZE, PSTR("T%.3u.%u H%.3u.%u G%u N%u\r\n"),
			
			int8_t tempRemainder = sensorResult.temperature % 10;
			if (tempRemainder < 0)
			{
				tempRemainder *= -1;
			}
			
			sprintf_P(buffor, PSTR("T%i.%i H%u.%u G%u N%u"), // Newline at the end is added in SendAlarmInfo
				sensorResult.temperature / 10, tempRemainder,
				sensorResult.humidity / 10, sensorResult.humidity % 10,
				resTemp, resHum);
			extConnector.uPuts(buffor);
			SendAlarmInfo();
		}
		
		ProcessUartInput();
		
		if (saveSettingsQueued)
		{
			saveSettingsQueued = 0;
			SaveSettings();
		}
	}
}

#pragma region Interrupts

uint8_t currentMultiplex = 0;

ISR (TIMER0_OVF_vect)
{
	currentMultiplex++;
	if (currentMultiplex > 2)
	currentMultiplex = 0;
	
	BIT_LOW(MULTIPLEX_1_PORT, MULTIPLEX_1_PIN);
	BIT_LOW(MULTIPLEX_2_PORT, MULTIPLEX_2_PIN);
	BIT_LOW(MULTIPLEX_3_PORT, MULTIPLEX_3_PIN);
	
	//Update LEDs and 7seg display
	sevSegMenu.DrawOutput(currentMultiplex);
	ledIndicators.UpdateLeds(currentMultiplex);
	
	switch(currentMultiplex)
	{
		case 0:
		BIT_HIGH(MULTIPLEX_1_PORT, MULTIPLEX_1_PIN);
		break;
		case 1:
		BIT_HIGH(MULTIPLEX_2_PORT, MULTIPLEX_2_PIN);
		break;
		case 2:
		BIT_HIGH(MULTIPLEX_3_PORT, MULTIPLEX_3_PIN);
		break;
		
		default:
		break;
	}
}

ISR(TIMER2_COMP_vect)
{
	timerHum.Tick();
	timerTemp.Tick();
	sensorRefreshTimer.Tick();
	speaker.TimerTick();
	sevSegMenu.Tick();
}

// Regulation override timer
ISR (TIMER1_COMPA_vect)
{
	DisableRegulationOverride();
}

/*// Menu timeout
ISR (TIMER1_COMPB_vect)
{
	// Return menu to the main screen with a beep, if it's not already there.
	
	if (currentlyDisplayed > Display_Temperature && currentlyDisplayed < Display_Humidity)
	{
		currentlyDisplayed = Display_Temperature;
		SPEAK_PLAY_TONE();
		
		// Update EEPROM with new settings if necessary
		settingsDirty = 1;
	}
	else if (currentlyDisplayed > Display_Humidity && currentlyDisplayed < Display_OtherAlarm)
	{
		currentlyDisplayed = Display_Humidity;
		SPEAK_PLAY_TONE();
		
		// Update EEPROM with new settings if necessary
		settingsDirty = 1;
	}
	else // We are already in the main menu!
	{
		// Disable timer now, since we are playing return tones with speaker in other cases
		TIMER1_STOP();
	}
	}*/
/*
ISR(BADISR_vect)
{
	alarm.SetAlarmFlag(AlarmType_SOFTWARE_FAIL);
}*/

#pragma endregion Interrupts

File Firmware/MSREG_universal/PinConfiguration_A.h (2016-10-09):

/*
 * PinConfiguration.h
 *
 * Created: 20-09-14 2:21:55 PM
 *  Author: Klocman
 */ 


#ifndef PINCONFIGURATION_H_
#define PINCONFIGURATION_H_

#define SEVSEG_A_PIN PINB4
#define SEVSEG_A_PORT PORTB
#define SEVSEG_A_DDR DDRB
#define SEVSEG_B_PIN PIND7
#define SEVSEG_B_PORT PORTD
#define SEVSEG_B_DDR DDRD
#define SEVSEG_C_PIN PINC4
#define SEVSEG_C_PORT PORTC
#define SEVSEG_C_DDR DDRC
#define SEVSEG_D_PIN PINC2
#define SEVSEG_D_PORT PORTC
#define SEVSEG_D_DDR DDRC
#define SEVSEG_E_PIN PINC1
#define SEVSEG_E_PORT PORTC
#define SEVSEG_E_DDR DDRC
#define SEVSEG_F_PIN PINB3
#define SEVSEG_F_PORT PORTB
#define SEVSEG_F_DDR DDRB
#define SEVSEG_G_PIN PINC5
#define SEVSEG_G_PORT PORTC
#define SEVSEG_G_DDR DDRC
#define SEVSEG_DP_PIN PINC3
#define SEVSEG_DP_PORT PORTC
#define SEVSEG_DP_DDR DDRC

#define MULTIPLEX_1_PIN PINB2
#define MULTIPLEX_2_PIN PINB1
#define MULTIPLEX_3_PIN PINB0
#define MULTIPLEX_1_DDR DDRB
#define MULTIPLEX_2_DDR DDRB
#define MULTIPLEX_3_DDR DDRB
#define MULTIPLEX_1_PORT PORTB
#define MULTIPLEX_2_PORT PORTB
#define MULTIPLEX_3_PORT PORTB

#define BUTTON_ADC 7

#define SENSOR_PIN PIND3
#define SENSOR_DDR DDRD
#define SENSOR_PORT PORTD
#define SENSOR_PORT_IN PIND

#define SPEAKER_PIN PIND2
#define SPEAKER_DDR DDRD
#define SPEAKER_PORT PORTD

#define TRIAC_HUM_PIN PINB5
#define TRIAC_HUM_DDR DDRB
#define TRIAC_HUM_PORT PORTB
#define TRIAC_TEMP_PORT PORTC
#define TRIAC_TEMP_DDR DDRC
#define TRIAC_TEMP_PIN PINC0

#define LEDS_1_PIN PIND4
#define LEDS_2_PIN PIND6
#define LEDS_3_PIN PIND5
#define LEDS_1_DDR DDRD
#define LEDS_2_DDR DDRD
#define LEDS_3_DDR DDRD
#define LEDS_1_PORT PORTD
#define LEDS_2_PORT PORTD
#define LEDS_3_PORT PORTD

#define OUTPUT_TRANSMIT_PIN PIND1
#define OUTPUT_TRANSMIT_DDR DDRD
#define OUTPUT_RECEIVE_PIN PIND0
#define OUTPUT_RECEIVE_DDR DDRD
#define OUTPUT_RECEIVE_PORT PORTD


#endif /* PINCONFIGURATION_H_ */

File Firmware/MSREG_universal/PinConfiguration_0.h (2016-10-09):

/*
 * PinConfiguration.h
 *
 * Created: 20-09-14 2:21:55 PM
 *  Author: Klocman
 */ 


#ifndef PINCONFIGURATION_H_
#define PINCONFIGURATION_H_

#define SEVSEG_A_PIN PIND3
#define SEVSEG_A_PORT PORTD
#define SEVSEG_A_DDR DDRD
#define SEVSEG_B_PIN PINB6
#define SEVSEG_B_PORT PORTB
#define SEVSEG_B_DDR DDRB
#define SEVSEG_C_PIN PINC1
#define SEVSEG_C_PORT PORTC
#define SEVSEG_C_DDR DDRC
#define SEVSEG_D_PIN PINC3
#define SEVSEG_D_PORT PORTC
#define SEVSEG_D_DDR DDRC
#define SEVSEG_E_PIN PINC4
#define SEVSEG_E_PORT PORTC
#define SEVSEG_E_DDR DDRC
#define SEVSEG_F_PIN PIND4
#define SEVSEG_F_PORT PORTD
#define SEVSEG_F_DDR DDRD
#define SEVSEG_G_PIN PINC0
#define SEVSEG_G_PORT PORTC
#define SEVSEG_G_DDR DDRC
#define SEVSEG_DP_PIN PINC2
#define SEVSEG_DP_PORT PORTC
#define SEVSEG_DP_DDR DDRC

#define MULTIPLEX_1_PIN PIND2
#define MULTIPLEX_2_PIN PIND5
#define MULTIPLEX_3_PIN PINB7
#define MULTIPLEX_1_DDR DDRD
#define MULTIPLEX_2_DDR DDRD
#define MULTIPLEX_3_DDR DDRB
#define MULTIPLEX_1_PORT PORTD
#define MULTIPLEX_2_PORT PORTD
#define MULTIPLEX_3_PORT PORTB

#define BUTTON_1_PIN PINB5
#define BUTTON_1_PORT PORTB
#define BUTTON_1_DDR DDRB
#define BUTTON_1_PININ PINB
#define BUTTON_2_PIN PINB3
#define BUTTON_2_PORT PORTB
#define BUTTON_2_DDR DDRB
#define BUTTON_2_PININ PINB

#define SENSOR_PIN PINB4
#define SENSOR_DDR DDRB
#define SENSOR_PORT PORTB
#define SENSOR_PORT_IN PINB

#define SPEAKER_PIN PINB2
#define SPEAKER_DDR DDRB
#define SPEAKER_PORT PORTB

#define TRIAC_TEMP_PIN PINC5
#define TRIAC_HUM_PIN PINB0
#define TRIAC_TEMP_DDR DDRC
#define TRIAC_HUM_DDR DDRB
#define TRIAC_TEMP_PORT PORTC
#define TRIAC_HUM_PORT PORTB

#define LEDS_1_PIN PINB1
#define LEDS_2_PIN PIND6
#define LEDS_3_PIN PIND7
#define LEDS_1_DDR DDRB
#define LEDS_2_DDR DDRD
#define LEDS_3_DDR DDRD
#define LEDS_1_PORT PORTB
#define LEDS_2_PORT PORTD
#define LEDS_3_PORT PORTD

#define OUTPUT_TRANSMIT_PIN PIND1
#define OUTPUT_TRANSMIT_DDR DDRD
#define OUTPUT_RECEIVE_PIN PIND0
#define OUTPUT_RECEIVE_DDR DDRD
#define OUTPUT_RECEIVE_PORT PORTD


#endif /* PINCONFIGURATION_H_ */

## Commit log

2016-10-09 Migrated project to Git
    [main_board_smd.brd, main_board_smd.sch]
2016-10-09 Added sensor connection information
    [sensor.sch]
2016-10-09 Added the case stickers
2016-10-10 Added photos of the finished, working device
2016-10-10 Added a photo of a fully assembled regulator with its back removed

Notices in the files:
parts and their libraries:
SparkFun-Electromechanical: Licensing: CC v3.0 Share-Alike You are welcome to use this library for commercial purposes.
